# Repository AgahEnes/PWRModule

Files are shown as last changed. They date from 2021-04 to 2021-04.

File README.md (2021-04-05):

# PWRModule
In this article we introduce our power distribution modules. These boards help to get rid of long and heavy power cables. Circuit boards are reliable for connection instead of cables. Some of them distribute power to parallel or serial ways and others regulates high voltage power to desired values.
 PCB's have XT60 connector inputs for battery and XT60 outputs to power sensors or other kind of stuffs on our UAVs. Every output connection getting power from Li-Po battery and regulate this for desired value. By using resistors we adjust the out voltage. Both of the boards for our UAVs and for regulate power.
 One of them designed for unmanned ground vehicle (UGV) and is capable of meeting the power requirements of the onboard sensors and autopilot. There is also a motor drive system that will enable the UAG to move.
For orders https://jlcpcb.com/RAT is reliable.

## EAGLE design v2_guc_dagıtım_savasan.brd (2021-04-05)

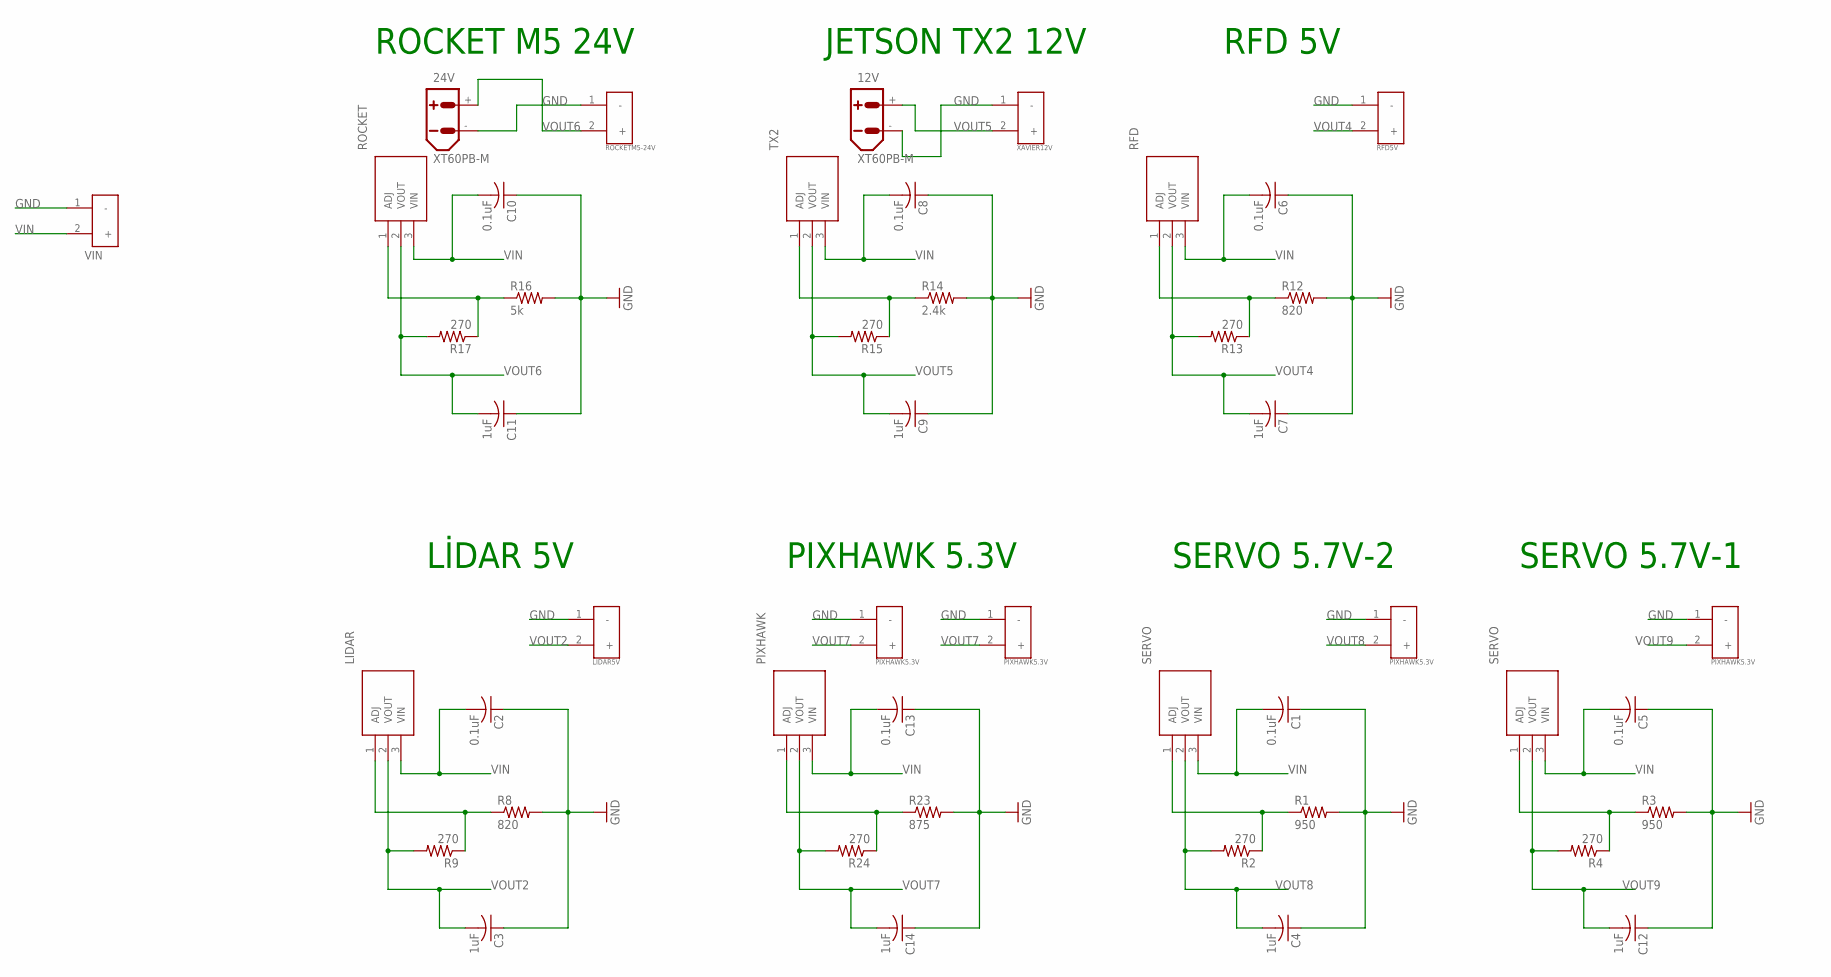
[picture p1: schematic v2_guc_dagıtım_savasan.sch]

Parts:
12V, 24V: XT60PB-M
C1, C2, C5, C6, C8, C10, C13: 0.1uF; C0402K
C3, C4, C7, C9, C11, C12, C14: 1uF; C0402K
IC5: LIDAR; TO254P470X1028X1955-3P
IC7: RFD; TO254P470X1028X1955-3P
IC8: TX2; TO254P470X1028X1955-3P
IC9: ROCKET; TO254P470X1028X1955-3P
IC13: PIXHAWK; TO254P470X1028X1955-3P
J3: VIN; AMASS_XT60-M
LIDAR5V: LIDAR5V; AMASS_XT60-M
PIXHAWK5.3V-1, PIXHAWK5.3V-2: PIXHAWK5.3V; AMASS_XT60-M
R1, R3: 950; R0805
R2, R4, R9, R13, R15, R17, R24: 270; R0805
R8, R12: 820; R0805
R14: 2.4k; R0805
R16: 5k; R0805
R23: 875; R0805
RFD5V: RFD5V; AMASS_XT60-M
ROCKETM5-24V: ROCKETM5-24V; AMASS_XT60-M
SERVO5.7V-1, SERVO5.7V-2: PIXHAWK5.3V; AMASS_XT60-M
SERVO-1, SERVO-2: SERVO; TO254P470X1028X1955-3P
TX2-12V: XAVIER12V; AMASS_XT60-M

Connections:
GND: 12V.-, 24V.-, C1.1, C2.1, C3.1, C4.1, C5.1, C6.1, C7.1, C8.1, C9.1, C10.1, C11.1, C12.1, C13.1, C14.1, J3.1 (-), LIDAR5V.1 (-), PIXHAWK5.3V-1.1 (-), PIXHAWK5.3V-2.1 (-), R1.2, R3.2, R8.2, R12.2, R14.2, R16.2, R23.2, RFD5V.1 (-), ROCKETM5-24V.1 (-), SERVO5.7V-1.1 (-), SERVO5.7V-2.1 (-), TX2-12V.1 (-)
unnamed: R1.1, R2.1, SERVO-2.1 (ADJ)
unnamed: R3.1, R4.1, SERVO-1.1 (ADJ)
unnamed: IC7.1 (ADJ), R12.1, R13.1
unnamed: IC5.1 (ADJ), R8.1, R9.1
unnamed: IC8.1 (ADJ), R14.1, R15.1
unnamed: IC9.1 (ADJ), R16.1, R17.1
unnamed: IC13.1 (ADJ), R23.1, R24.1
VIN: C1.2, C2.2, C5.2, C6.2, C8.2, C10.2, C13.2, IC5.3 (VIN), IC7.3 (VIN), IC8.3 (VIN), IC9.3 (VIN), IC13.3 (VIN), J3.2 (+), SERVO-1.3 (VIN), SERVO-2.3 (VIN)
VOUT2: C3.2, IC5.2 (VOUT), LIDAR5V.2 (+), R9.2
VOUT4: C7.2, IC7.2 (VOUT), R13.2, RFD5V.2 (+)
VOUT5: 12V.+, C9.2, IC8.2 (VOUT), R15.2, TX2-12V.2 (+)
VOUT6: 24V.+, C11.2, IC9.2 (VOUT), R17.2, ROCKETM5-24V.2 (+)
VOUT7: C14.2, IC13.2 (VOUT), PIXHAWK5.3V-1.2 (+), PIXHAWK5.3V-2.2 (+), R24.2
VOUT8: C4.2, R2.2, SERVO5.7V-2.2 (+), SERVO-2.2 (VOUT)
VOUT9: C12.2, R4.2, SERVO5.7V-1.2 (+), SERVO-1.2 (VOUT)

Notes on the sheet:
ROCKET M5 24V
JETSON TX2 12V
RFD 5V
LİDAR 5V
PIXHAWK 5.3V
SERVO 5.7V-2
SERVO 5.7V-1

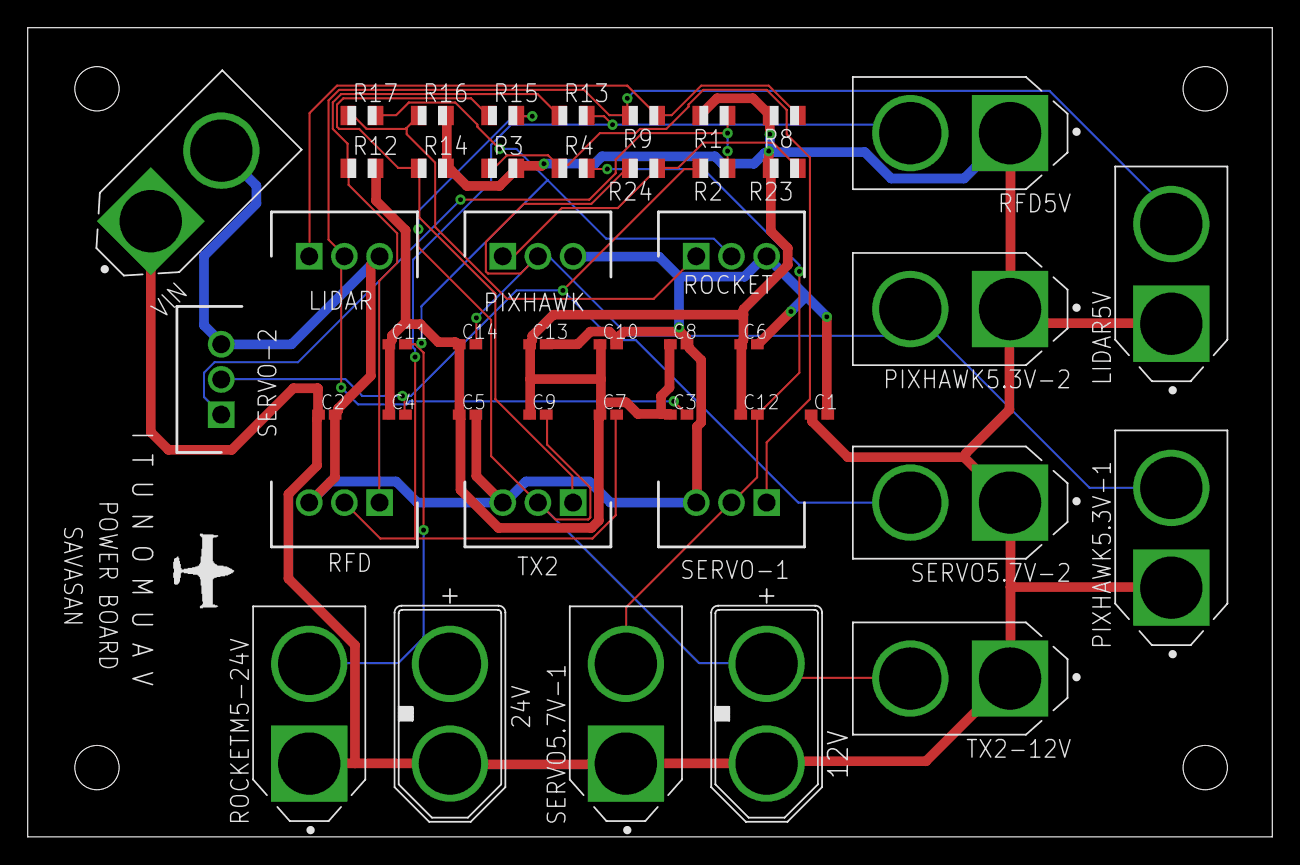
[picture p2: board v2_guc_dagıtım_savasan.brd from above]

Board: 2 copper layers, 89.8 x 58.4 mm, 46 parts (0 on the bottom side), 16 nets.

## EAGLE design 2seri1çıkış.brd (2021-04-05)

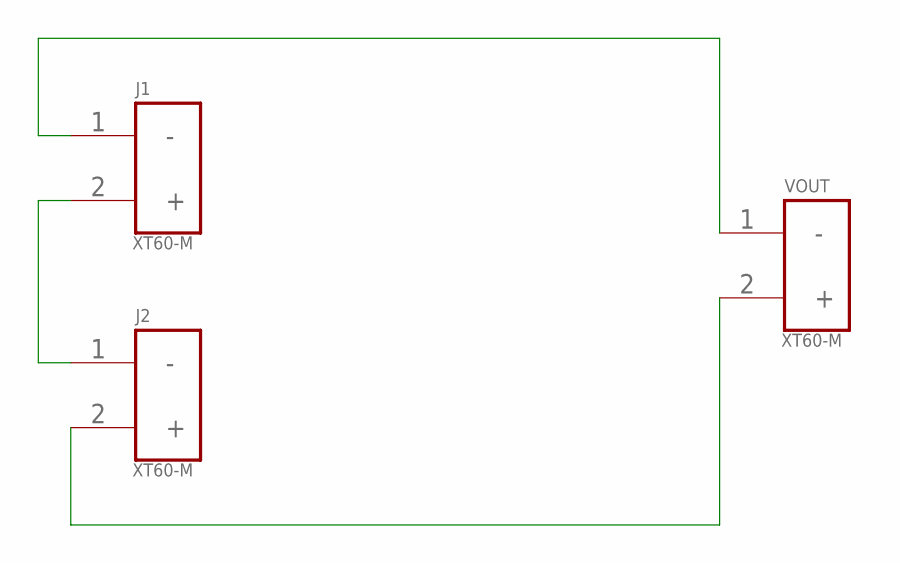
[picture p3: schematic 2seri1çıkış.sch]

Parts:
J1, J2: XT60-M; AMASS_XT60-M
VOUT: XT60-M; AMASS_XT60-M

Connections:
unnamed: J1.2 (+), J2.1 (-)
unnamed: J2.2 (+), VOUT.2 (+)
unnamed: J1.1 (-), VOUT.1 (-)

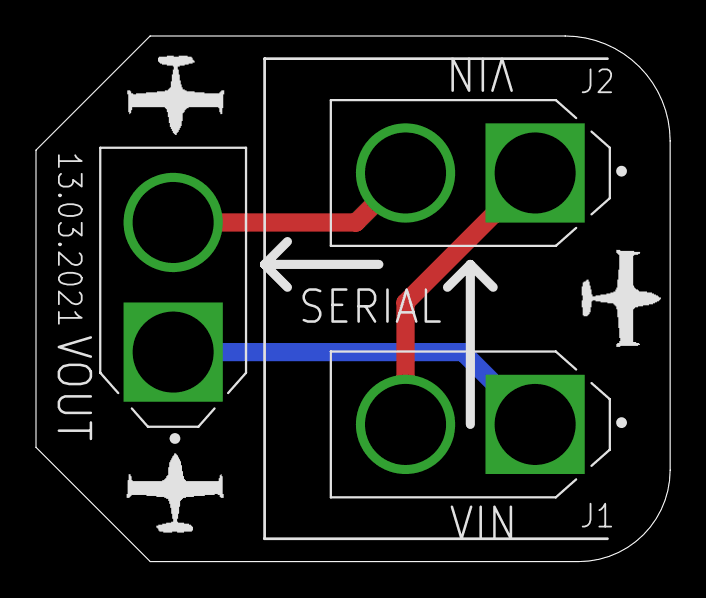
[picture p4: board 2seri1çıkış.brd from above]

Board: 2 copper layers, 35.2 x 29.2 mm, 3 parts (0 on the bottom side), 3 nets.

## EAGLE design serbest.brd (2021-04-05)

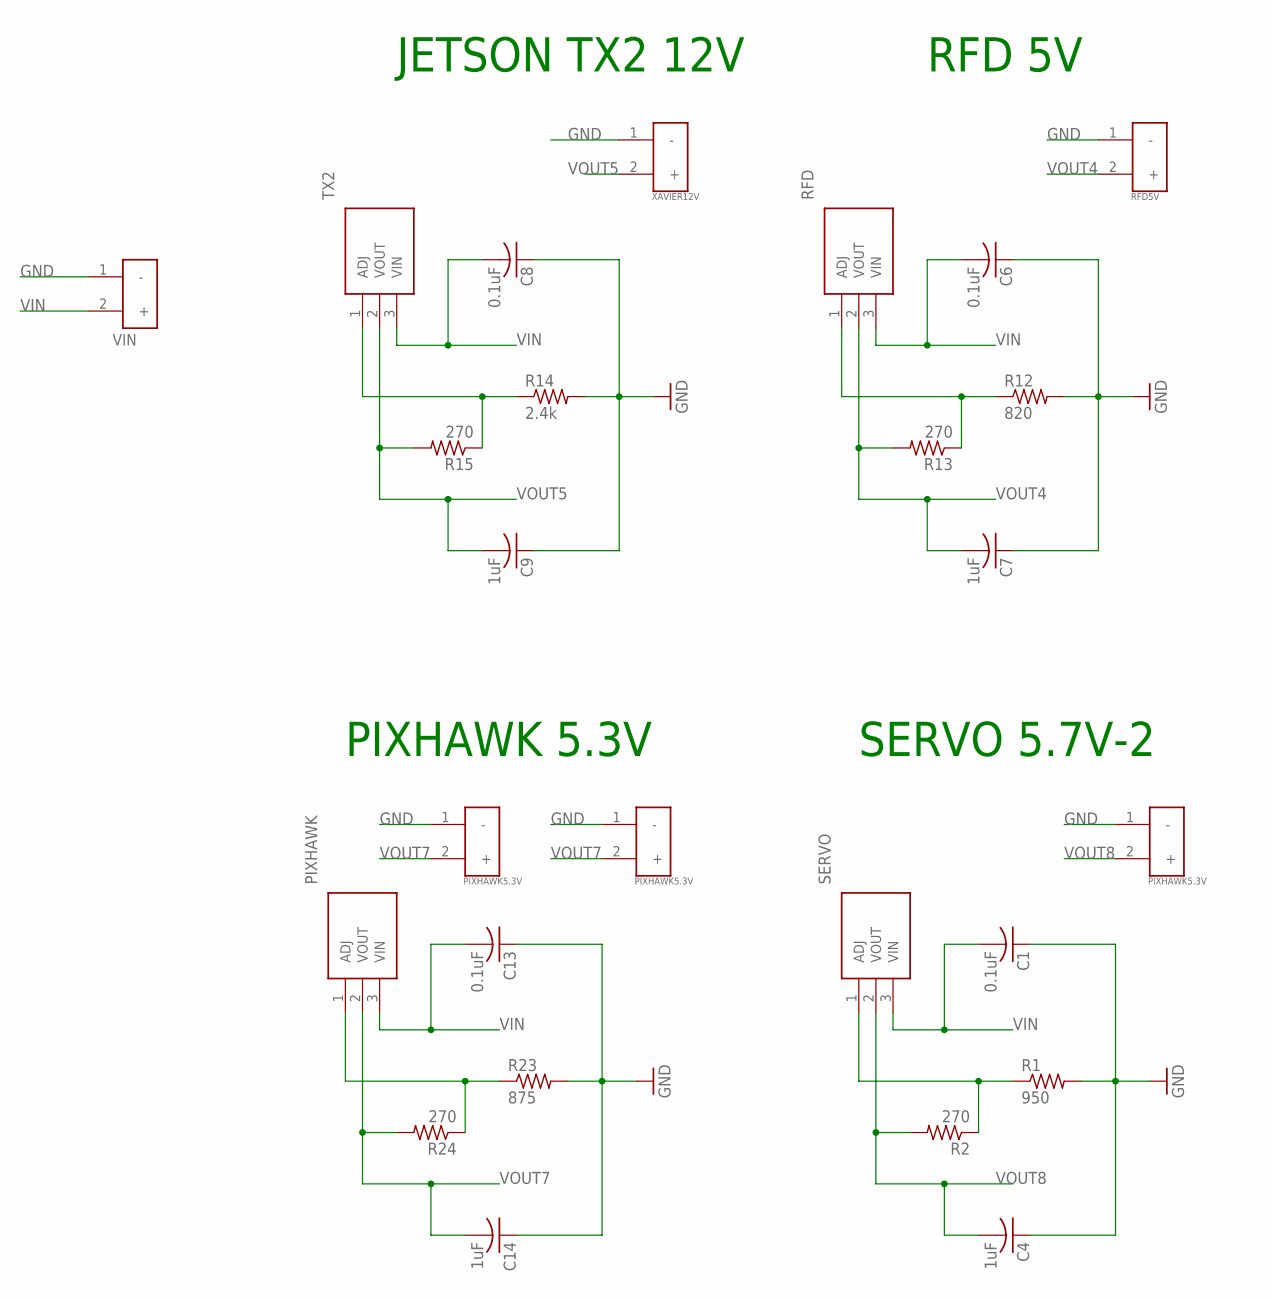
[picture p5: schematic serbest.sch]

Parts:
C1, C6, C8, C13: 0.1uF; C0402K
C4, C7, C9, C14: 1uF; C0402K
J3: VIN; AMASS_XT60-M
PIXHAWK: PIXHAWK; TO254P470X1028X1955-3P
PIXHAWK5.3V-1, PIXHAWK5.3V-2: PIXHAWK5.3V; AMASS_XT60-M
R1: 950; R0805
R2, R13, R15, R24: 270; R0805
R12: 820; R0805
R14: 2.4k; R0805
R23: 875; R0805
RFD: RFD; TO254P470X1028X1955-3P
RFD5V: RFD5V; AMASS_XT60-M
SERVO5.7V-2: PIXHAWK5.3V; AMASS_XT60-M
SERVO-2: SERVO; TO254P470X1028X1955-3P
TX2: TX2; TO254P470X1028X1955-3P
TX2-12V: XAVIER12V; AMASS_XT60-M

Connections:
GND: C1.1, C4.1, C6.1, C7.1, C8.1, C9.1, C13.1, C14.1, J3.1 (-), PIXHAWK5.3V-1.1 (-), PIXHAWK5.3V-2.1 (-), R1.2, R12.2, R14.2, R23.2, RFD5V.1 (-), SERVO5.7V-2.1 (-), TX2-12V.1 (-)
unnamed: R1.1, R2.1, SERVO-2.1 (ADJ)
unnamed: R12.1, R13.1, RFD.1 (ADJ)
unnamed: R14.1, R15.1, TX2.1 (ADJ)
unnamed: PIXHAWK.1 (ADJ), R23.1, R24.1
VIN: C1.2, C6.2, C8.2, C13.2, J3.2 (+), PIXHAWK.3 (VIN), RFD.3 (VIN), SERVO-2.3 (VIN), TX2.3 (VIN)
VOUT4: C7.2, R13.2, RFD.2 (VOUT), RFD5V.2 (+)
VOUT5: C9.2, R15.2, TX2.2 (VOUT), TX2-12V.2 (+)
VOUT7: C14.2, PIXHAWK.2 (VOUT), PIXHAWK5.3V-1.2 (+), PIXHAWK5.3V-2.2 (+), R24.2
VOUT8: C4.2, R2.2, SERVO5.7V-2.2 (+), SERVO-2.2 (VOUT)

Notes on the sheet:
JETSON TX2 12V
RFD 5V
PIXHAWK 5.3V
SERVO 5.7V-2

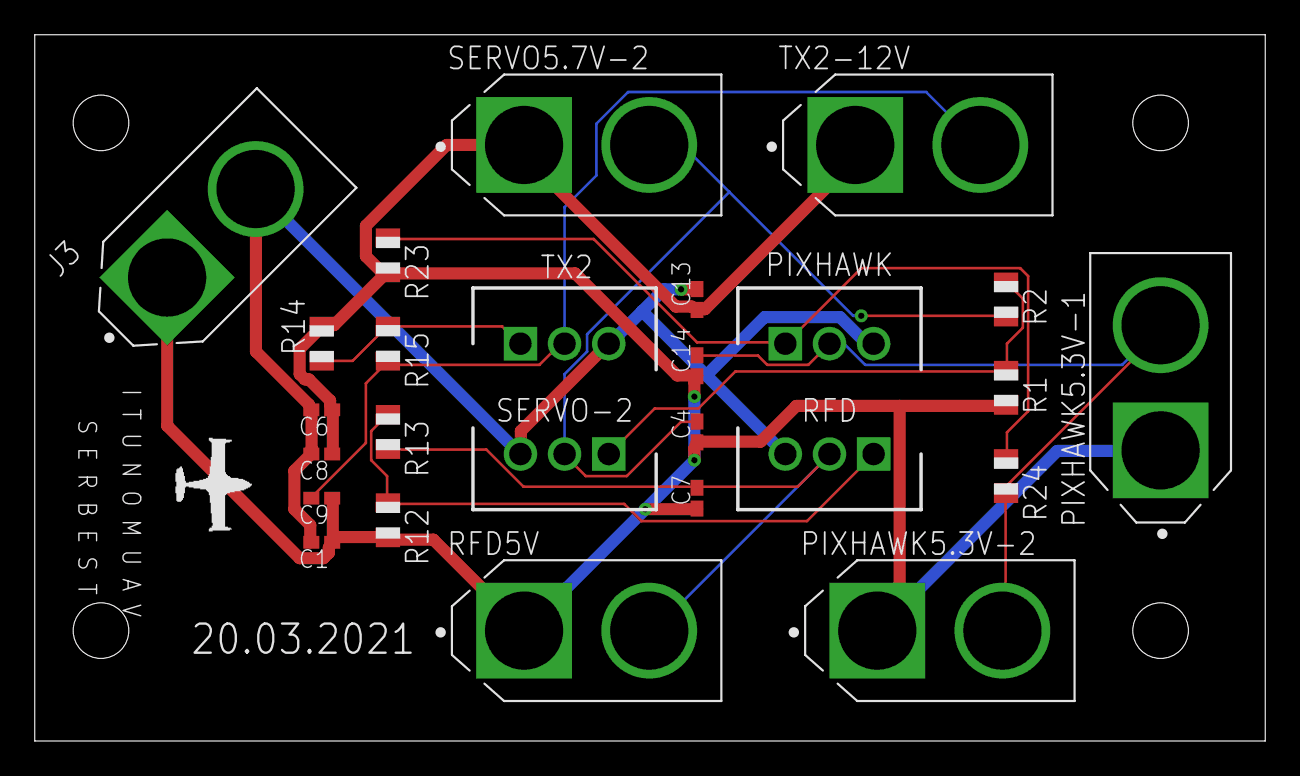
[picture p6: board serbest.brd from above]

Board: 2 copper layers, 70.8 x 40.6 mm, 26 parts (0 on the bottom side), 10 nets.

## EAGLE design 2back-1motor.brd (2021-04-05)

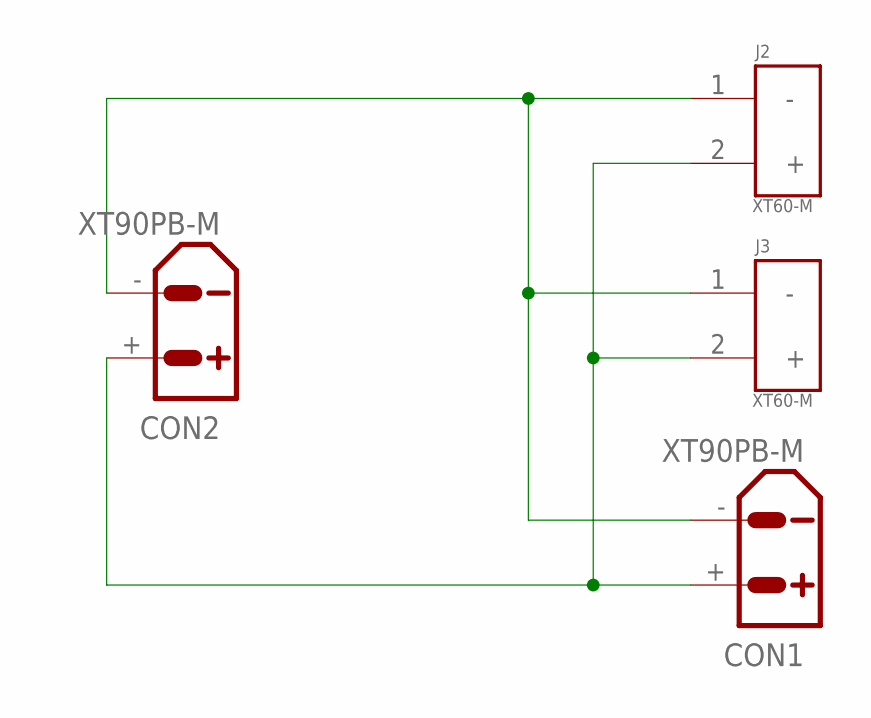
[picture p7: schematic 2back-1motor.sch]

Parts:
CON1, CON2: XT90PB-M
J2, J3: XT60-M; AMASS_XT60-M

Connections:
unnamed: CON1.-, CON2.-, J2.1 (-), J3.1 (-)
unnamed: CON1.+, CON2.+, J2.2 (+), J3.2 (+)

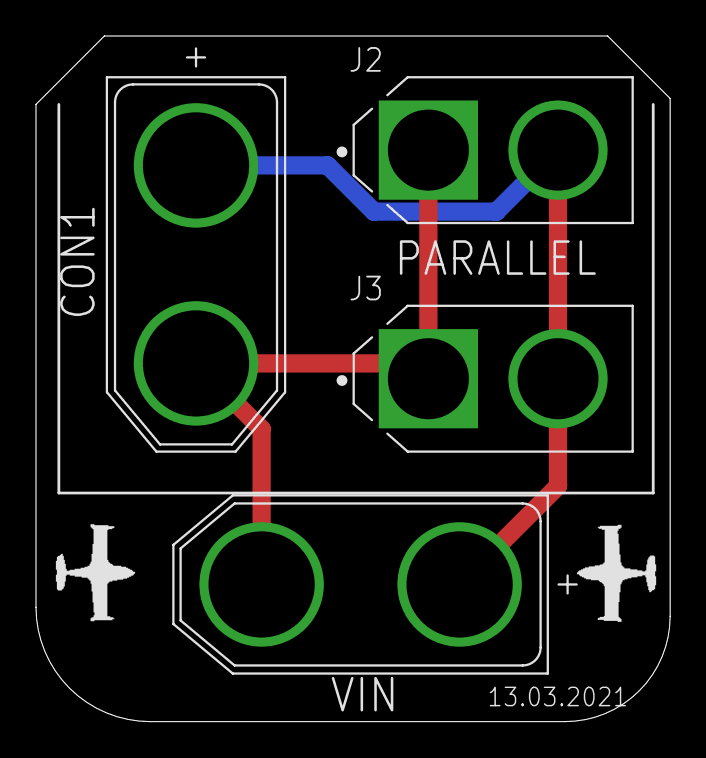
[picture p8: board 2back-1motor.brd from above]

Board: 2 copper layers, 35.2 x 38.1 mm, 4 parts (0 on the bottom side), 2 nets.

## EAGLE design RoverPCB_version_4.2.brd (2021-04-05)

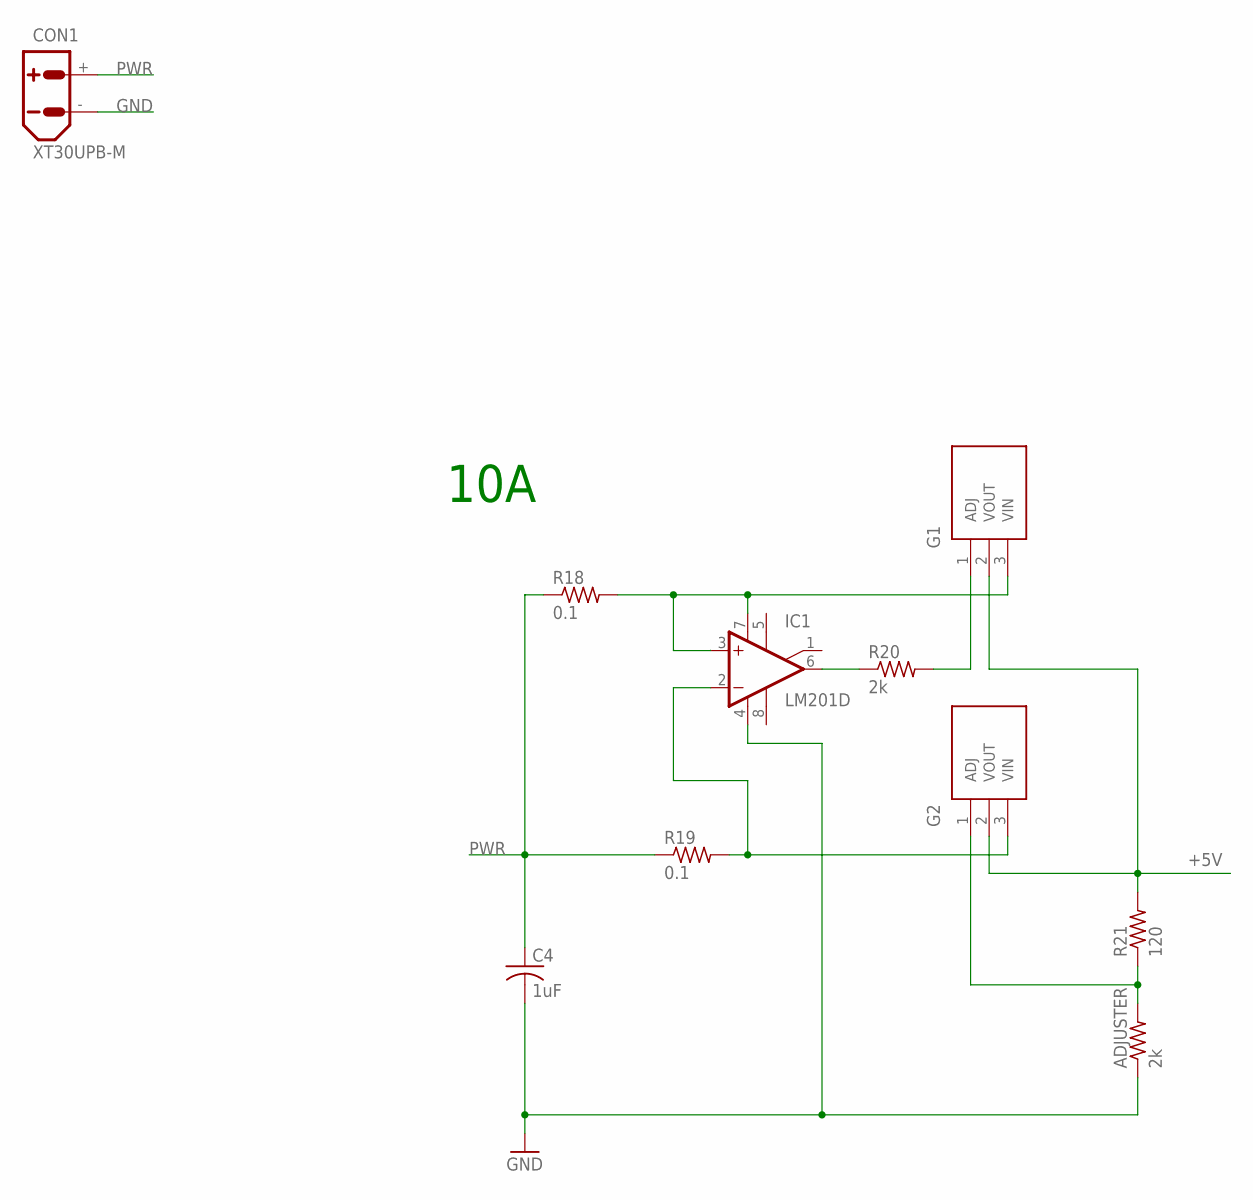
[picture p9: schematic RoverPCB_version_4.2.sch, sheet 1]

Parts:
ADJUSTER: 2k; 0204/5
C4: 1uF; C0402K
CON1: XT30UPB-M
IC1: LM201D; SO08
IC11: G1; TO254P470X1028X1955-3P
IC12: G2; TO254P470X1028X1955-3P
R18, R19: 0.1; M1206
R20: 2k; R0805
R21: 120; R0805

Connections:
+5V: IC11.2 (VOUT), IC12.2 (VOUT), R21.2; also elsewhere on the board
GND: ADJUSTER.1, C4.2, CON1.-, IC1.4 (V-); also elsewhere on the board
unnamed: IC11.1 (ADJ), R20.2
unnamed: IC1.6 (OUT), R20.1
unnamed: ADJUSTER.2, IC12.1 (ADJ), R21.1
unnamed: IC1.3 (+IN), IC1.7 (V+), IC11.3 (VIN), R18.2
unnamed: IC1.2 (-IN), IC12.3 (VIN), R19.2
PWR: C4.1, CON1.+, R18.1, R19.1; also elsewhere on the board

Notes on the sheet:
10A

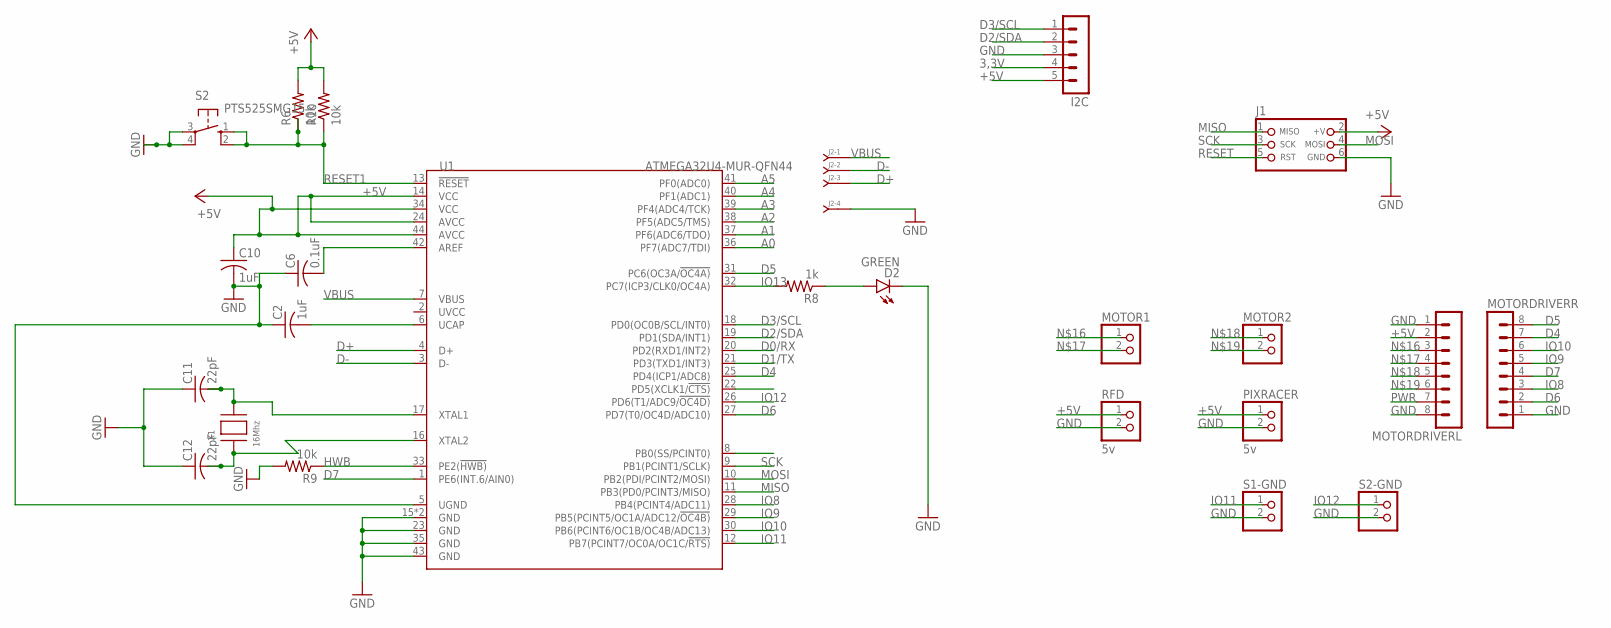
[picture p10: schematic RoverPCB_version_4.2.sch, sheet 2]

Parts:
C2, C10: 1uF; C0805
C6: 0.1uF; C0805
C11, C12: 22pF; C0805
D2: GREEN; LED-0603
I2C: MA05-1
J1: CON_HEADER_PRG_AVR_ICSP-PTH; HEADER_PRG_2X03
J2: J-04-SIP-100; SIP-100-04
MOTOR1, MOTOR2: PINHD-1X2; 1X02
MOTORDRIVERL: MA08-1
MOTORDRIVERR: MA08-1
PIXRACER: 5v; 1X02
R6, R9, R10: 10k; R0805
R8: 1k; R0805
RFD: 5v; 1X02
S1-GND, S2-GND: PINHD-1X2; 1X02
S2: PTS525SMG15; SMG15
U1: ATMEGA32U4-MUR-QFN44; QFN44G-0.5-7X7MM
X1: 16Mhz; NX5032

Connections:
3,3V: I2C.4
+5V: C10.1, I2C.5, J1.2 (+V), MOTORDRIVERL.2, PIXRACER.1, R6.2, R10.2, RFD.1, U1.14 (VCC), U1.24 (AVCC), U1.34 (VCC), U1.44 (AVCC); also elsewhere on the board
A0: U1.36 (PF7(ADC7/TDI))
A1: U1.37 (PF6(ADC6/TDO))
A2: U1.38 (PF5(ADC5/TMS))
A3: U1.39 (PF4(ADC4/TCK))
A4: U1.40 (PF1(ADC1))
A5: U1.41 (PF0(ADC0))
D0/RX: U1.20 (PD2(RXD1/INT2))
D1/TX: U1.21 (PD3(TXD1/INT3))
D2/SDA: I2C.2, U1.19 (PD1(SDA/INT1))
D3/SCL: I2C.1, U1.18 (PD0(OC0B/SCL/INT0))
D4: MOTORDRIVERR.7, U1.25 (PD4(ICP1/ADC8))
D5: MOTORDRIVERR.8, U1.31 (PC6(OC3A/!OC4A))
D6: MOTORDRIVERR.2, U1.27 (PD7(T0/OC4D/ADC10))
D7: MOTORDRIVERR.4, U1.1 (PE6(INT.6/AIN0))
D+: J2.3, U1.4 (D+)
D-: J2.2, U1.3 (D-)
GND: C2.1, C6.1, C10.2, C11.1, C12.1, D2.C, I2C.3, J1.6 (GND), J2.4, MOTORDRIVERL.1, MOTORDRIVERL.8, MOTORDRIVERR.1, PIXRACER.2, R9.2, RFD.2, S1-GND.2, S2.3, S2.4, S2-GND.2, U1.5 (UGND), U1.15 (GND), U1.23 (GND), U1.35 (GND), U1.43 (GND), U1.TAB (GND); also elsewhere on the board
HWB: R9.1, U1.33 (PE2(!HWB))
IO8: MOTORDRIVERR.3, U1.28 (PB4(PCINT4/ADC11))
IO9: MOTORDRIVERR.5, U1.29 (PB5(PCINT5/OC1A/ADC12/!OC4B))
IO10: MOTORDRIVERR.6, U1.30 (PB6(PCINT6/OC1B/OC4B/ADC13))
IO11: S1-GND.1, U1.12 (PB7(PCINT7/OC0A/OC1C/!RTS))
IO12: S2-GND.1, U1.26 (PD6(T1/ADC9/!OC4D))
IO13: R8.2, U1.32 (PC7(ICP3/CLK0/OC4A))
MISO: J1.1 (MISO), U1.11 (PB3(PD0/PCINT3/MISO))
MOSI: J1.4 (MOSI), U1.10 (PB2(PDI/PCINT2/MOSI))
unnamed: D2.A, R8.1
unnamed: C11.2, U1.17 (XTAL1), X1.P$2
unnamed: C2.2, U1.6 (UCAP)
unnamed: C12.2, U1.16 (XTAL2), X1.P$1
unnamed: C6.2, U1.42 (AREF)
unnamed: MOTOR1.1, MOTORDRIVERL.3
unnamed: MOTOR1.2, MOTORDRIVERL.4
unnamed: MOTOR2.1, MOTORDRIVERL.5
unnamed: MOTOR2.2, MOTORDRIVERL.6
PWR: MOTORDRIVERL.7; also elsewhere on the board
RESET: J1.5 (RST)
RESET1: R6.1, R10.1, S2.1 (S), S2.2 (S), U1.13 (!RESET)
SCK: J1.3 (SCK), U1.9 (PB1(PCINT1/SCLK))
VBUS: J2.1, U1.7 (VBUS)

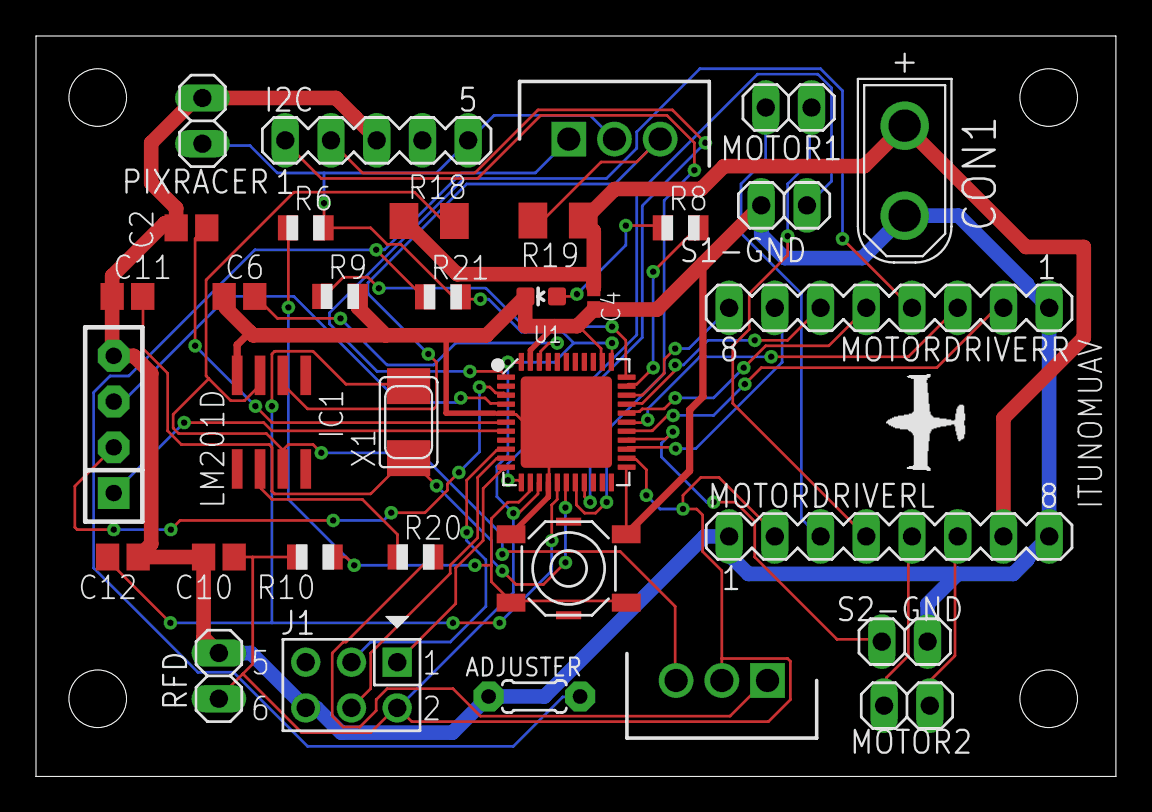
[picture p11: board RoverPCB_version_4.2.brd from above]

Board: 2 copper layers, 60.0 x 41.1 mm, 34 parts (0 on the bottom side), 37 nets.

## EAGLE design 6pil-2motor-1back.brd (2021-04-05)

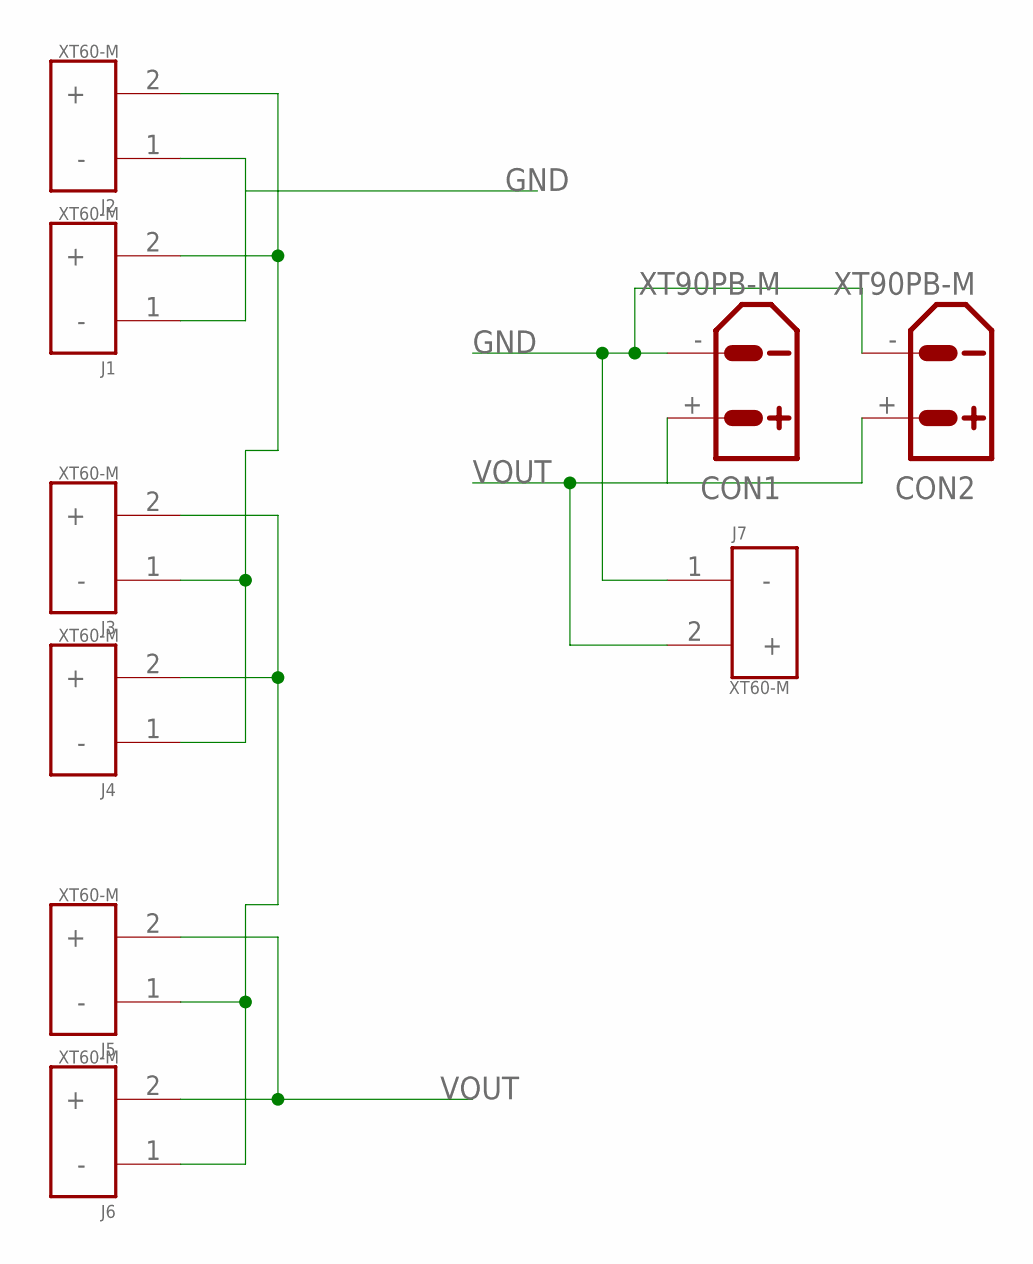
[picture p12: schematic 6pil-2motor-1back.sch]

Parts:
CON1, CON2: XT90PB-M
J1, J2, J3, J4, J5, J6, J7: XT60-M; AMASS_XT60-M

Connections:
GND: CON1.-, CON2.-, J1.1 (-), J2.1 (-), J7.1 (-)
unnamed: J1.2 (+), J2.2 (+), J3.1 (-), J4.1 (-)
unnamed: J3.2 (+), J4.2 (+), J5.1 (-), J6.1 (-)
VOUT: CON1.+, CON2.+, J5.2 (+), J6.2 (+), J7.2 (+)


Board: 2 copper layers, 72.4 x 53.3 mm, 9 parts (0 on the bottom side), 4 nets.

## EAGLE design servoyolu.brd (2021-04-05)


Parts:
J1, J2, J3, J4, J5, J6, J7, J8, J9, J10, J11, J12, J13, J14, J16, J18: 455-1750-1-ND; 1X03
J15: XT60-M; AMASS_XT60-M

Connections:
GND: J1.3, J2.3, J3.3, J4.3, J5.3, J6.3, J7.3, J8.3, J9.3, J10.3, J11.3, J12.3, J13.3, J14.3, J15.1 (-), J16.3, J18.3
unnamed: J8.1, J18.1
unnamed: J1.1, J9.1
unnamed: J2.1, J10.1
unnamed: J3.1, J11.1
unnamed: J4.1, J12.1
unnamed: J5.1, J13.1
unnamed: J6.1, J14.1
unnamed: J7.1, J16.1
unnamed: J8.2, J9.2, J10.2, J11.2, J12.2, J13.2, J14.2, J15.2 (+), J16.2

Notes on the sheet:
out


Board: 2 copper layers, 65.7 x 27.9 mm, 17 parts (0 on the bottom side), 10 nets.

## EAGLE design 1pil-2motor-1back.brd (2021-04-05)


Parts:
CON2, CON3: XT90PB-M
J1: XT60-M; AMASS_XT60-M
VIN: XT90PB-M

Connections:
unnamed: CON2.+, CON3.+, J1.2 (+), VIN.+
unnamed: CON2.-, CON3.-, J1.1 (-), VIN.-


Board: 2 copper layers, 41.6 x 35.5 mm, 4 parts (0 on the bottom side), 2 nets.

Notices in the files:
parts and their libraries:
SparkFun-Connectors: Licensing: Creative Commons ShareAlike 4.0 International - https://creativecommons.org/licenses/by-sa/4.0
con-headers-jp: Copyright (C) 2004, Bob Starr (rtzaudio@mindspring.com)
